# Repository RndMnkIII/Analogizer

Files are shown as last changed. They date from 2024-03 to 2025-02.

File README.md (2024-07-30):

<p float="left">
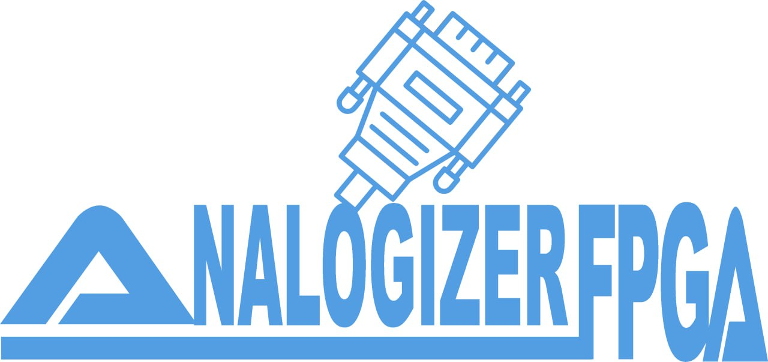
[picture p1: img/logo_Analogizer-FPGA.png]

</p>

Ahora tienes toda la información de Analogizer-FPGA en la [Wiki](https://github.com/RndMnkIII/Analogizer/wiki)

Now you have all the information about Analogizer-FPGA in the [Wiki](https://github.com/RndMnkIII/Analogizer/wiki)

[Tienda Online/Online Store](https://www.analogizer-fpga.com)

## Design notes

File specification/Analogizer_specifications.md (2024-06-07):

# Analogizer Specifications

## Hardware 
* Based on the ADV7123 RGB DAC. It uses 6 bits per color component. It can output video signal with SOG. Supports video frequencies up to 140MHz. 
* RGBS, RGsB, YPbPr, Y/C, RGBHV video output via VGA connector.
* USB 3 connector for SNAC7 adapters that allows you to connect native game controllers. * Connects to the Analogue Pocket using the cartridge port. 
* External 5V power using USB3 C port. Necessary for powering the active Y/C adapter, activating RGB mode on TV with SCART and powering native game controllers.
* A/B switch to alternate signal layout for SNAC devices.
u* SOG (Analogizer R2) switch to activate Sync On Green functionality.

## Basics
 The basis of the Analogizer adapter is to expand the possibilities of the Analogue Pocket portable console in two fundamental aspects. On the one hand
 allow obtaining an analog video output from the video signals generated by the core before being adapted to the characteristics
 Pocket display. This means using the resolution, refresh rates, sync signals, etc. of the original core as it was.
 implemented to replicate the original system. No preprocessing of any kind is applied beyond adapting certain signals to be able to generate the
 different video outputs (RGBS,RGsB,YPbPr, Y/C,RGBHV). This video signal will be compatible with different types of screens, the main objective
 CRT displays with an operating frequency of 15KHz and with different types of video input: SCART RGB, SCART SVideo, SCART Composite, video
 component with YPbPr, SVideo, composite video. Additionally, using a scandoubler module, there will be the possibility of viewing the video using
 SVGA monitors. On the other hand, we want to add the possibility of using native game controllers with the Pocket cores. This is achieved using
 the already established base of official SNAC adapters for MiSTEr that use the SNAC7 protocol and USB 3 type A connector. Analogizer today
 offers SNAC support for 1/2 players for NeoGeo DB15, NES, SNES type controllers. Additionally, it offers 1-player support for PCEngine controllers.
 2 and 6 buttons. This support expands to 4 players using NEC's 5-player multitap adapter. For PCEngine type controls and NEC multitap
 It is necessary to use a wiring harness between the SNAC adapter and the Analogizer due to certain limitations of the Analogizer adapter (it does not have freedom
 to configure SNAC signals as input or output on an individual level and certain signals have a fixed output or input configuration) due to how
 The Pocket's cartridge expansion port works. The adapter has a side switch marked A/B, the default position being A. This
 affects the layout of signals for the SNAC port. Configuration A supports the types of controls listed above. B is reserved for
 future expansions, for example to support PSX controllers. All of this functionality consumes logic resources directly from the Pocket's Cyclone V FPGA.
 that must be shared with the implementation of the core in question to which you want to add support.

## Video output signals
 The main use of Analogizer is that it allows you to obtain different types of analog video signals. It is essential to implement all of them, especially
 the Y/C output for SVideo and composite video, taking into account that most of the CRT TV devices available to users only have this
 video inputs, followed by users with TVs with component video inputs and TVs with SCART inputs. SVGA output is considered accessory for users
 They do not have CRT TV screens but they do have SVGA video monitors.
 In order of video output quality on CRT, the following are recommended:
 * SCART RGB
 * YPbpr component video (requires R2 version of Analogizer with SOG)
 * Y/C SVideo
 * Y/C composite video
 * SVGA

 This table establishes the type of cable and/or adapter necessary depending on the type of video output:
 | VIDEO SIGNAL    | CABLE AND/OR ADAPTER               | COMMENTS                                                                                                                                |
 | :-------------: | :--------------------------------: | :-------------------------------------------------------------------------------------------------------------------------------------: |
 | RGBS            | VGA TO SCART                       | There are specific models that also incorporate a jack-type audio connector. See main repository for more information.                  |
 | RGBS            | VGA TO BNC                         | For CRT models with BNC type inputs. These are normally PVM type professional range screens.                                            |
 | RGsB            | VGA TO SCART                       | Similar to YPbPr but uses RGB channels with sync on G channel. Requires Analogizer R2 with SOG switch (ON position)                     |
 | RGsB            | VGA TO component                   | Similar to YPbPr but uses RGB channels with sync on G channel. Requires Analogizer R2 with SOG switch (ON position)                     |
 | YPbPr           | VGA TO component                   | This cable has 3 RCA cables on the other end. Requires the use of Analogizer R2 with SOG switch (ON position)                           |
 | Y/C             | Active Y/C adapter + cable         | SVideo cable with MiniDIN4 connector or composite video cable with RCA connector.                                                       |
 | RGBHV           | VGA                                | VGA cable to connect directly to a monitor of this type.                                                                                |

## SNAC adapters for controllers
 The second most important functionality that Analogizer offers is that it allows you to use SNAC7 adapters with a USB 3 (type A) connector that already exist in Analogizer with certain limitations.
 This means that you can currently use native controllers for Neogeo DB15, NES, SNES and PCEngine 2btn and 6btn connectors and the NEC 5-player MultiTap adapter (currently 
 you are limited to 4 players by the Analogizer interface). That said, there are countless designs that in most cases will work without problems. In the README of the main Analogizer repository, the different types of adapters compatible with Analogizer will be added, there are versions for both 1 controller and 2 controllers (DB15, NES, SNES). For controls of the type
 PCEngine is also required to have a wiring harness specifically created for Analogizer (it is available for sale in the Analogizer online store and the pcb design is public for users interested in building it themselves). At one end it is connected to the SNAC adapter through a USB 3 female type A connector and at the other end it is
 connects Analogizer with a USB 3 male type A connector. USB 3 female-male extension cables can be used at the convenience of users and is the recommended connection method to avoid
 Excessive stress on the connectors if all these adapters are connected together directly.

 It must be taken into account that the Blue212 type SNAC adapters use two boards (one of them is specific to the native control and has the native connector but does not have its own circuitry). The other board is a common design for all controls and is connected directly to the previous one, it provides all the electronics to convert voltage levels between the controls signals.
 and Analogizer.

## Analogizer interface (development)
The first modification that must be added to the original core code is to enable the Pocket's cartridge port. To do this we must edit the `core.json` file located in the same location as the core bitstream and set `"cartridge_adapter"` to the value`0`:

```
{
  "core": {
    "magic": "APF_VER_1",
    ...
        "framework": {
      "target_product": "Analogue Pocket",
      ...
         "hardware": {
           "link_port": false,
           "cartridge_adapter": 0
         },
```

As the creator of Analogizer I have also developed an interface in Verilog that encapsulates all the functionality in a single module that must be instantiated.
This module is the one that connects the different parts involved so that everything works correctly.

This module communicates with the adapter directly through the Pocket's cartridge expansion port. This port is available in the framework
of Analogue openFPGA for the developer, using the following signals instantiated in the highest level module as follows:

```
module apf_top \(
...
        ///////////////////////////////////////////////////
        // cartridge interface
        // switches between 3.3v and 5v mechanically
        // output enable for multibit translators controlled by PIC32

        // GBA AD[15:8]
        inout   wire    [7:0]   cart_tran_bank2,
        output  wire            cart_tran_bank2_dir,

        // GBA AD[7:0]
        inout   wire    [7:0]   cart_tran_bank3,
        output  wire            cart_tran_bank3_dir,

        // GBA A[23:16]
        inout   wire    [7:0]   cart_tran_bank1,
        output  wire            cart_tran_bank1_dir,

        // GBA [7] PHI#
        // GBA [6] WR#
        // GBA [5] RD#
        // GBA [4] CS1#/CS#
        //     [3:0] unwired
        inout   wire    [7:4]   cart_tran_bank0,
        output  wire            cart_tran_bank0_dir,

        // GBA CS2#/RES#
        inout   wire            cart_tran_pin30,
        output  wire            cart_tran_pin30_dir,
        // when GBC cart is inserted, this signal when low or weak will pull GBC /RES low with a special circuit
        // the goal is that when unconfigured, the FPGA weak pullups won't interfere.
        // thus, if GBC cart is inserted, FPGA must drive this high in order to let the level translators
        // and general IO drive this pin.
        output  wire            cart_pin30_pwroff_reset,

        // GBA IRQ/DRQ
        inout   wire            cart_tran_pin31,
        output  wire            cart_tran_pin31_dir,
		...
  \)
``` 

Normally the `openFPGA_Pocket_Analogizer` module is instantiated at a lower level, where the core module is instantiated.
The only thing that is required is to connect the required signals between the core of the machine that is going to be executed and the instance of the module.
Analogizer:

| SIGNAL | TYPE | WIDTH | FUNCTION |
| :---: | :---: | :---: | :---: |
| MASTER_CLK_FREQ | PARAMETER| | This parameter is used to calculate the delay in timing signals for SNAC |
| i_clk | INPUT | 1 | main clock. It can be the core master clock or the video clock. |
| i_rst | INPUT | 1 | reset signal active at high. Resets the interface and keeps the cartridge port in the default state |
| i_ena | INPUT | 1 | enable signal. If disabled, it keeps the cartridge port in the default state |
| analog_video_type | INPUT | 4 | Select Analogizer video output through the video output port |
| R | INPUT | 8 | color channel R. Internally it is reduced to the 6 bits with the highest weight |
| G | INPUT | 8 | color channel G. Internally it is reduced to the 6 bits with the highest weight |
| B | INPUT | 8 | color channel B. Internally it is reduced to the 6 bits with the highest weight |
| HBlank | INPUT | 1 | horizontal blanking signal |
| VBlank | INPUT | 1 | vertical blanking signal |
| BLANKn | INPUT | 1 | active low composite blanking signal \(ADV7123 requires it for RGBS, RGsB video output\) |
| Hsync | INPUT | 1 | horizontal synchronization signal |
| Vsync | INPUT | 1 | vertical synchronization signal |
| Csync | INPUT | 1 | composite synchronization signal. The generation of this signal is specific to each core |
| video_clk | INPUT | 1 | video clock for the ADV7123. Depending on the core, this signal may be the same as i_clk or another specific |
| PALFLAG | INPUT | 1 | Y/C specific signal. Allows you to adapt SVideo and composite video to PAL\(=1\) or NTSC\(=0\) |
| MUFLAG | INPUT | 1 | specific Y/C signal \(DEBUG\). Modifies the way the phase accumulator is calculated (default =0) |
| CHROMA_ADD | INPUT | 5 | specific Y/C signal \(DEBUG\). Allows you to adjust the value of the phase accumulator in the development phase  |
| CHROMA_MULT | INPUT | 5 | specific Y/C signal \(DEBUG\). Allows you to adjust the value of the phase accumulator in the development phase  |
| CHROMA_PHASE_INC | INPUT | 40 | Y/C specific signal. Tuned phase accumulator step value for core frequency |
| COLORBURST_RANGE | INPUT | 27 | Y/C specific signal. Tuned color burst value for core video frequency |
| ce_divider | INPUT | 3 | Scandoubler RGBHV specifies signal. Pixel clock divider. Use value that best fits the image |
| conf_AB | INPUT | 1 | SNAC signal. Configuration A\(=0\) or B\(=1\) for SNAC. It must match the position of the A/B switch |
| game_cont_type | INPUT | 5 | SNAC signal. Specifies if SNAC commands are not used and if what type are used (See interact.json file) |
| p1_btn_state | OUTPUT | 16 | SNAC signal. Status of SNAC control buttons for player1 \(ST,SEL,R3,L3,R2,L2,R1,L1,Y,X,B,A,R,L,D,U\) |
| p2_btn_state | OUTPUT | 16 | SNAC signal. Status of SNAC control buttons for player2 \(ST,SEL,R3,L3,R2,L2,R1,L1,Y,X,B,A,R,L,D,U\) |
| p3_btn_state | OUTPUT | 16 | SNAC signal. Status of SNAC control buttons for player3 \(ST,SEL,R3,L3,R2,L2,R1,L1,Y,X,B,A,R,L,D,U\) |
| p4_btn_state | OUTPUT | 16 | SNAC signal. Status of SNAC control buttons for player4 \(ST,SEL,R3,L3,R2,L2,R1,L1,Y,X,B,A,R,L,D,U\) |
| cart_tran_bank2 | I/O | 8 | Interface with the cartridge port. Connects directly to the signals of the higher level module |
| cart_tran_bank2_dir | OUTPUT | 1 | Interface with the cartridge port. Connects directly to the signals of the higher level module |
| cart_tran_bank3 | I/O | 8 | Interface with the cartridge port. Connects directly to the signals of the higher level module |
| cart_tran_bank3_dir | OUTPUT | 1 | Interface with the cartridge port. Connects directly to the signals of the higher level module |
| cart_tran_bank1 | I/O | 8 | Interface with the cartridge port. Connects directly to the signals of the higher level module |
| cart_tran_bank1_dir | OUTPUT | 1 | Interface with the cartridge port. Connects directly to the signals of the higher level module |
| cart_tran_bank0 | I/O | 4 | Interface with the cartridge port. Connects directly to the signals of the higher level module |
| cart_tran_bank0_dir | OUTPUT | 1 | Interface with the cartridge port. Connects directly to the signals of the higher level module |
| cart_tran_pin30 | I/O | 1 | Interface with the cartridge port. Connects directly to the signals of the higher level module |
| cart_tran_pin30_dir | OUTPUT | 1 | Interface with the cartridge port. Connects directly to the signals of the higher level module |
| cart_pin30_pwroff_reset| OUTPUT | 1 | Interface with the cartridge port. Connects directly to the signals of the higher level module |
| cart_tran_pin31 | I/O | 1 | Interface with the cartridge port. Connects directly to the signals of the higher level module |
| cart_tran_pin31_dir | OUTPUT | 1 | Interface with the cartridge port. Connects directly to the signals of the higher level module |
| o_stb | OUTPUT | 1 | Interface with the cartridge port. Connects directly to the signals of the higher level module |

So that the user can modify the Analogizer options, three groups of options are established. These options are usually set in the `interact.js` file which is in the same location as the core bitstream. This may change in the case of cores that have different options depending on the game you want to load:

```
{
  "interact": {
    "magic": "APF_VER_1",
    "variables": [
       {
        "name": "SNAC Adapter",
        "id": 43,
        "type": "list",
        "enabled": true,
        "persist": true,
        "address": "0xA0000000",
        "defaultval": "0x00",
        "mask": "0xFFFFFFE0",
        "options": [
            {
            "value": "0x00",
            "name": "None"
            },
            {
            "value": "0x01",
            "name": "DB15 Normal"
            },
            {
            "value": "0x02",
            "name": "NES"
            },
            {
            "value": "0x03",
            "name": "SNES"
            },
            {
            "value": "0x04",
            "name": "PCE 2BTN"
            },
            {
            "value": "0x05",
            "name": "PCE 6BTN"
            },
            {
            "value": "0x06",
            "name": "PCE Multitap"
            },
            {
              "value": "0x09",
              "name": "DB15 Fast"
            },
            {
              "value": "0x0B",
              "name": "SNES A,B<->X,Y"
            }
        ]
    },
    {
        "name": "SNAC Controller Assignment",
        "id": 44,
        "type": "list",
        "enabled": true,
        "persist": true,
        "address": "0xA0000000",
        "defaultval": "0x00",
        "mask": "0xFFFFFC3F",
        "options": [
            {
              "value": "0x0",
              "name": "SNAC -> P1"
            },
            {
              "value": "0x40",
              "name": "SNAC -> P2"
            },
            {
              "value": "0x80",
              "name": "SNAC P1,P2->P1,P2"
            },
            {
              "value": "0xC0",
              "name": "SNAC P1,P2->P2,P1"
            },
            {
              "value": "0x200",
              "name": "SNAC P1,P2->P3,P4"
            },
            {
              "value": "0x100",
              "name": "SNAC P1-P4->P1-P4"
            },
            {
              "value": "0x140",
              "name": "SNAC P1-P2->P1-P2"
            },
            {
              "value": "0x180",
              "name": "SNAC P1-P2->P3-P4"
            }
        ]
    },
    {
        "name": "Analogizer Video Out",
        "id": 45,
        "type": "list",
        "enabled": true,
        "persist": true,
        "address": "0xA0000000",
        "defaultval": "0x0",
        "mask": "0xFFFFC3FF",
        "options": [
            {
              "value": "0x0",
              "name": "RGBS"
            },
            {
              "value": "0x0400",
              "name": "RGsB"
            },
            {
              "value": "0x0800",
              "name": "YPbPr"
            },
            {
              "value": "0x0C00",
              "name": "Y/C NTSC"
            },
            {
              "value": "0x1400",
              "name": "Scandoubler RGBHV"
            },
            {
              "value": "0x2000",
              "name": "RGBS,Pocket OFF"
            },
            {
              "value": "0x2400",
              "name": "RGsB,Pocket OFF"
            },
            {
              "value": "0x2800",
              "name": "YPbPr,Pocket OFF"
            },            {
              "value": "0x2C00",
              "name": "Y/C NTSC,Pocket OFF"
            },
            {
              "value": "0x3400",
              "name": "Scandoubler,Pocket OFF"
            }
        ]
    },
    ...
        ],
    "messages": []
  }
}
```

In a schematic way, these would be the different options that can be selected for Analogizer:

```
  SNAC Adapter
    |                            FUNCTION                    VALUE (hex) WIDTH ADDRESS    MASK       MASKED VALUE
    +----------- None            disables SNAC interface     0x0         5     0xA0000000 0xFFFFFFE0 0x00        
    +----------- DB15 Normal     1/2 players                 0x1         5     0xA0000000 0xFFFFFFE0 0x01        
    +----------- NES             1/2 players                 0x2         5     0xA0000000 0xFFFFFFE0 0x02        
    +----------- SNES            1/2 players                 0x3         5     0xA0000000 0xFFFFFFE0 0x03         
    +----------- PCE 2BTN        1 player                    0x4         5     0xA0000000 0xFFFFFFE0 0x04         
    +----------- PCE 6BTN        1 player                    0x5         5     0xA0000000 0xFFFFFFE0 0x05         
    +----------- PCE Multitap    allows 4 players            0x6         5     0xA0000000 0xFFFFFFE0 0x06         
    +----------- DB15 Fast       uses faster sampling        0x9         5     0xA0000000 0xFFFFFFE0 0x09         
    +----------- SNES A,B<->X,Y  swap A,B X,Y buttons        0xB         5     0xA0000000 0xFFFFFFE0 0x0B         
``` 

```
  SNAC Controller Assignment 
    |                              FUNCTION                                       VALUE (hex) WIDTH ADDRESS    MASK       MASKED VALUE
    +----------- SNAC -> P1        SNAC controller to P1                          0x0         4     0xA0000000 0xFFFFFC3F 0x000                 
    +----------- SNAC -> P2        SNAC controller to P2                          0x1         4     0xA0000000 0xFFFFFC3F 0x040           
    +----------- SNAC P1,P2->P1,P2 SNAC cont1,cont2 to P1,P2                      0x2         4     0xA0000000 0xFFFFFC3F 0x080           
    +----------- SNAC P1,P2->P2,P1 SNAC cont1,cont2 to P2,P1                      0x3         4     0xA0000000 0xFFFFFC3F 0x0C0           
    +----------- SNAC P1,P2->P3,P4 SNAC cont1,cont2 to P3,P4 (only for 4P cores)  0x8         4     0xA0000000 0xFFFFFC3F 0x200           
    +----------- SNAC P1-P4->P1-P4 SNAC cont1-cont4 to P1-P4 (only for 4P cores)  0x9         4     0xA0000000 0xFFFFFC3F 0x100           
    +----------- SNAC P1-P2->P1-P2 SNAC cont1-cont2 to P1-P2 (only for 4P cores)  0xA         4     0xA0000000 0xFFFFFC3F 0x140           
    +----------- SNAC P1-P2->P3-P4 SNAC cont1-cont2 to P3-P4 (only for 4P cores)  0xB         4     0xA0000000 0xFFFFFC3F 0x180                     
```

```
  Analogizer Video Out
    |                                   FUNCTION                    VALUE (hex) WIDTH ADDRESS    MASK       MASKED VALUE 
    +----------- RGBS                   idem                        0x0         4     0xA0000000 0xFFFFC3FF 0x0000       
    +----------- RGsB                   idem                        0x1         4     0xA0000000 0xFFFFC3FF 0x0400       
    +----------- YPbPr                  idem                        0x2         4     0xA0000000 0xFFFFC3FF 0x0800       
    +----------- Y/C NTSC               idem                        0x3         4     0xA0000000 0xFFFFC3FF 0x0C00       
    +----------- Y/C PAL                idem                        0x4         4     0xA0000000 0xFFFFC3FF 0x1000       
    +----------- Scandoubler RGBHV      idem                        0x5         4     0xA0000000 0xFFFFC3FF 0x1400       
    +----------- RGBS,Pocket OFF        idem, blanks Pocket screen  0x8         4     0xA0000000 0xFFFFC3FF 0x2000       
    +----------- RGsB,Pocket OFF        idem, blanks Pocket screen  0x9         4     0xA0000000 0xFFFFC3FF 0x2400       
    +----------- YPbPr,Pocket OFF       idem, blanks Pocket screen  0xA         4     0xA0000000 0xFFFFC3FF 0x2800       
    +----------- Y/C NTSC,Pocket OFF    idem, blanks Pocket screen  0xB         4     0xA0000000 0xFFFFC3FF 0x2C00       
    +----------- Y/C PAL,Pocket OFF     idem, blanks Pocket screen  0xC         4     0xA0000000 0xFFFFC3FF 0x3000       
    +----------- Scandoubler,Pocket OFF idem, blanks Pocket screen  0xD         4     0xA0000000 0xFFFFC3FF 0x3400         
```

A range of bridge addresses must be selected in the Pocket framework. In the example, address 0xA0000000 has been reserved for Analogizer.
The interaction in the code is up to the developer, in this example it would look like this:

```
  // for bridge write data, we just broadcast it to all bus devices
  // for bridge read data, we have to mux it
  // add your own devices here
  always @(*) begin
    casex (bridge_addr)
      default: begin
        bridge_rd_data <= 0;
      end
      32'h2xxxxxxx: begin
        bridge_rd_data <= sd_read_data;
      end
      32'hA0000000: begin //Analogizer settings
        bridge_rd_data <= {18'h0,analogizer_settings};
      end
      32'hF8xxxxxx: begin
        bridge_rd_data <= cmd_bridge_rd_data;
      end
    endcase
  end
```

```
 always @(posedge clk_74a) begin
    if (reset_delay > 0) begin
      reset_delay <= reset_delay - 1;
    end

    if (bridge_wr) begin
      casex (bridge_addr)
        32'h0: begin
          ioctl_download <= bridge_wr_data[0];
        end
        32'h4: begin
          save_download <= bridge_wr_data[0];
        end
        ...
        /*[ANALOGIZER_HOOK_BEGIN]*/
		32'hA0000000: analogizer_settings  <=  bridge_wr_data[13:0];
	    /*[ANALOGIZER_HOOK_END]*/
        ...
      endcase
    end
  end
```

It may be necessary to synchronize the reading of the options, when using different clock domains:

```
  /*[ANALOGIZER_HOOK_BEGIN]*/
  //Pocket Menu settings
  reg [13:0] analogizer_settings = 0;
  wire [13:0] analogizer_settings_s;

  synch_3 #(.WIDTH(14)) sync_analogizer(analogizer_settings, analogizer_settings_s, clk_sys_42_95);

  always @(*) begin
    snac_game_cont_type   = analogizer_settings_s[4:0];
    snac_cont_assignment  = analogizer_settings_s[9:6];
    analogizer_video_type = analogizer_settings_s[13:10];
  end
  /*[ANALOGIZER_HOOK_END]*/
```

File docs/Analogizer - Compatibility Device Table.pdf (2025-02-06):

USER | MANUFACTURER | MODEL | SCREEN TYPE | COLOR SYSTEM | VIDEO INPUT | STATUS | YEAR @rndmnkiii | SONY | PVM-9044D | CRT HR Trinitron (450 lines) | PAL/SECAM,NTSC | Y/C(4pin MiniDIN); COMPOSITE, RGBS, YPBPR,RGsB (BNC) | NTSC and PAL works @rndmnkiii | SONY | KV-M1420E | CRT Trinitron | PAL | RGBS (SCART), COMPOSITE (RCA) | PAL works(RGB SCART,composite), NTSC works(RGB SCART)
@HardBit | SONY | KV-14FV300 | CRT | NTSC | YPBPR | OK @Denymetanol | SONY | EVM-9010PR | CRT | PAL | COMPOSITE | OK @Denymetanol | NEC | MultiSync LV15m | LCD | SVGA | RGBHV | OK @RetroQuest | SONY | CRT | NTSC | COMPOSITE | OK @unlovedhomie | NEC | MultiSync 1560V+ | LCD | SVGA | RGBHV | OK @unlovedhomie | SONY | CRT | NTSC | YPBPR | YPbPr don't sync
| JVC | AV-27120 27" | CRT | NTSC | COMPOSITE SVIDEO YPbPr | ? | sept 2000
@romanista | SHARP | 37GT 27S | CRT | PAL | RGBS SCART | OK

USER | CABLE TYPE | WEBSITE | NOTES
rndmnkiii | VGA TO SCART | https://manuferhi.com/p/cable-rgb-scart-for-mister-sidi-and-n-go | built-in audio jack cable, 470ohms in CSYNC resistor
rndmnkiii | VGA TO SCART | https://ultimatemister.com/product/rgb-scart-cable/ | built-in audio jack cable, 470ohms in CSYNC resistor
rndmnkiii | VGA TO BNC COAX. | https://www.amazon.es/dp/B0CWP9X1Z8?ref=ppx_yo2ov_dt_b_fed_asin_title | used to connect to a Sony PVM, needs 4 cables:R,G,B,Csync
rndmnkiii | VGA TO VGA | any cable
rndmnkiii | VGA gender changer | any adapter
rndmnkiii | RCA TO BNC | https://www.amazon.es/dp/B017R6XXFS?ref=ppx_yo2ov_dt_b_fed_asin_title | used to connect Mike Simone Y/C adapter (composite) to a Sony PVM
rndmnkiii | SVIDEO | https://www.amazon.es/dp/B000MM3LNO?ref=ppx_yo2ov_dt_b_fed_asin_title&th=1 | used to connect Mike Simone Y/C adapter (SVideo) to a Sony PVM

USER | PSX SNAC TYPE | PORTS 2 | https://analogizer-fpga.com/products/psx-snac-adapter-usb-3-type-a-male-female-cable WEBSITE | NOTES @rndmnkiii
@rndmnkiii | DB15 | 2 | https://ultimatemister.com/product/snac-db15-neogeo/
@rndmnkiii | NES,SNES,PCEngine/TurboGrafx-16 | 1-2 | https://ultimatemister.com/product/ultimate-snac-mini-hdmi/ | needs matching game controller cable
@rndmnkiii | DB15,NES,SNES,PCEngine/TurboGrafx-16 | 1-2 | https://antoniovillena.com/product/splitter-for-official-mister/ | specific models for each game controller
@rndmnkiii | NES,SNES,PCEngine/TurboGrafx-16 | 1-2 | https://misterfpga.co.uk/product/mister-snac-adapter-usb/ | needs matching game controller board: https://misterfpga.co.uk/product/mister-snac-controller-adapters/
@rndmnkiii | PSX | 2 | https://misterfpga.co.uk/product/mister-snac-playstation-psx-adapter/
@rndmnkiii | PSX | 2 | https://manuferhi.com/p/mister-snac-playstation-adapter

USER | TYPE | WEBSITE | NOTES
rndmnkiii | 8Bitdo SNES Retroreceiver | https://www.8bitdo.com/retro-receiver-snes-sfc-classic/ | Allows, using a SNES SNAC adapter, connect a wide selection of Bluetooth game controllers to Analogizer: * 8BitDo Bluetooth Classic controllers and arcade sticks: https://shop.8bitdo.com/collections/bluetooth-controller * Xbox Bluetooth® controller, DualShock 3, DualShock 4, DualShock 4 Pro * Wiimote, Wii U Pro, Switch Joy-Cons, Switch Pro
rndmnkiii | 8Bitdo PSX Retroreceiver | https://www.8bitdo.com/retro-receiver-for-ps/ | Allows, using a PSX SNAC adapter, connect a wide selection of Bluetooth game controllers to Analogizer: * 8BitDo Bluetooth Classic controllers and arcade sticks: https://shop.8bitdo.com/collections/bluetooth-controller * Xbox Bluetooth® controller, DualShock 3, DualShock 4, DualShock 4 Pro * Wiimote, Wii U Pro, Switch Joy-Cons, Switch Pro
rndmnkiii | JAMMA TO SNAC DB15 Uses JAMMA Arcade cabinet controls as aDB15 SNAC two player controller (don't needs a DB15 SNAC adapter to be used with Analogizer). THIS ADAPTER IS INTENDED FOR ADVANCED USER, don't use it If you are not comfortable regulating voltage sources or you don't have basic knowledge of electronics. You could damage the adapter or the Pocket itself.
rndmnkiii | GENESIS/MEGADRIVE PAD TO NEOGEO ADAPTER Allows to connect a 3/6 button Genesis game controller to a DB15 SNAC adapter. The DB15 SNAC adapter must be output 5v throught the DB15 power pin. | https://www.ebay.es/itm/156101614172

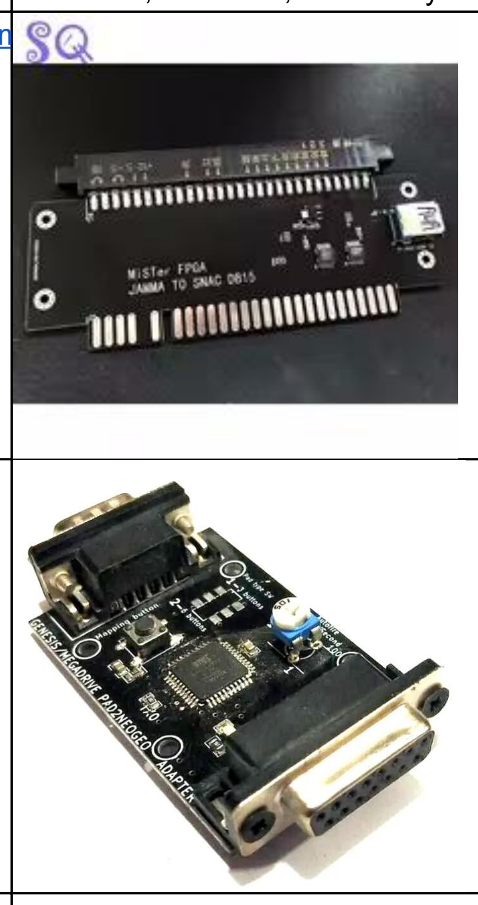
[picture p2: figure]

https://es.aliexpress.com/item/1005004883345268.html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

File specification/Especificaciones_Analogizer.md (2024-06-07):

# Especificaciones de Analogizer
## Hardware
* Basado en el DAC RGB ADV7123. Utiliza 6 bits por componente de color. Puede generar salida con SOG.Admite frecuencias de video de hasta 140MHz.
* Salida de video RGBS,RGsB,YPbPr,Y/C,RGBHV a través de conector VGA.
* Conector USB 3 para adaptores SNAC7 que permite conectar mandos de juegos nativos.
* Se conecta a la Analogue Pocket Utilizando el puerto de cartuchos.
* Alimentación externa de 5V utilizando puerto USB3 C. Necesaria para alimentacion de adaptador activo Y/C, activación de modo RGB en TV con SCART y alimentación de mandos de juegos nativos.
* Interruptor A/B para alternar disposicion de señales para dispositivos SNAC.
* Interruptor SOG (Analogizer R2) para activar funcionalidad Sync On Green.

## Fundamentos
 El fundamento del adaptador Analogizer es ampliar las posibilidades de la consola portatil Pocket de Analogue en dos aspectos fundamentales. Por un lado
 permitir obtener una salida de video analógica a partir de las señales de video que genera el core antes de ser adaptadas a las características
 de visualización de la Pocket. Esto implica usar la resolución, frecuencias de refresco, señales de sincronismo, etc del core original tal como fue
 implementado para replicar el sistema original. No se aplica preprocesado de ningún tipo más allá de adaptar ciertas señales para poder generar las
 diferentes salidas de video (RGBS,RGsB,YPbPr, Y/C,RGBHV). Esta señal de video será compatible con diferentes tipos de pantalla, el objetivo principal
 pantallas CRT con una frecuencia de funcionamiento de 15KHz y con diferentes tipos de entrada de video: SCART RGB, SCART SVideo, SCART Composite, video
 por componentes con YPbPr, SVideo, video compuesto. Además utilizando un módulo scandoubler se habre la posibilidad de visualizar el video utilizando
 monitores SVGA. Por otro lado se quiere añadir la posibilidad de utilizar mandos de juegos nativos con los cores de la Pocket. Esto se logra utilizando
 la base ya establecida de adaptadores SNAC oficiales para MiSTEr que utilizan el protocolo SNAC7 y conector USB 3 del tipo A. Analogizer en la actualidad
 ofrece soporte SNAC para 1/2 jugadores para los mandos de tipo NeoGeo DB15, NES, SNES. Adicionalmente ofrece soporte para 1 jugador para mandos PCEngine de
 2 y 6 botones. Este suporte se amplia a 4 jugadores utilizando el adaptador multitap de 5 jugadores de NEC. Para los mandos de tipo PCEngine y el multitap NEC
 es necesario utilizar un arnés de cableado entre el adaptador SNAC y el Analogizer debido a ciertas limitaciones del adaptador Analogizer (no tiene libertad
 para configurar las señales SNAC como de entrada o salida a nivel individual y ciertas señales tienen un configuración fija de salida o entrada) debidas a como
 funciona el puerto de expansión de cartuchos de la Pocket. El adaptador dispone de un switch lateral marcado con A/B, siendo la posición por defecto la A. Esto
 afecta a la disposicion de las señales para el puerto SNAC. Con la configuración A se da soporte a los tipos de mandos antes enumerados. La B se reserva para
 futuras ampliciones, por ejemplo para dar soporte a los mandos PSX. Toda esta funcionalidad consume recursos lógicos directamente de la FPGA Cyclone V de la Pocket
 que deben ser compartidos con la implementación del core en cuestión al que se le quiere añadir soporte.

## Señales de salida de video
 La principal utilidad de Analogizer es que permite obtener diferentes tipos de señales de video analógicas. Es fundamental implementar todas ellas, especialmente
 la salida Y/C para SVideo y video compuesto, teniendo en cuenta que la mayor parte de los dispositivos CRT TV de los que disponen los usuarios solo dispone de esta
 entradas de video, seguidos por los usuarios con TV con entrada de video por componentes y TV con entrada SCART. La salida SVGA se considera accesoria para usuarios
 que no disponen de pantallas de TV CRT pero si disponen de monitores de video SVGA.
 Por orden de calidad de salida de video en CRT se recomiendan: 

 * SCART RGB
 * Video por componentes YPbpr (requiere versión R2 de Analogizer con SOG)
 * Y/C SVideo
 * Y/C video compuesto
 * SVGA
  
 En esta tabla se establece el tipo de cable y/o adaptador necesario en función del tipo de salida de video:
 
 | SEÑAL DE VIDEO  | CABLE Y/O ADAPTADOR                | COMENTARIOS                                                                                                                           |
 | :-------------: | :--------------------------------: | :-----------------------------------------------------------------------------------------------------------------------------------: |
 | RGBS            | VGA TO SCART                       | Hay modelos especificos que incorporan tambien el conector de audio de tipo jack. Ver repositorio principal para mas información.     |
 | RGBS            | VGA TO BNC                         | Para modelos de CRT con entradas de tipo BNC. Normalmente se trata de pantallas de gama profesional de tipo PVM.                      |
 | RGsB            | VGA TO SCART                       | Parecido a YPbPr pero usa canales RGB con el sync en el canal G. Necesita Analogizer R2 con interruptor SOG (posicion ON)             | 
 | RGsB            | VGA TO component                   | Parecido a YPbPr pero usa canales RGB con el sync en el canal G. Necesita Analogizer R2 con interruptor SOG (posicion ON)             | 
 | YPbPr           | VGA TO component                   | esta cable tiene 3 cables RCA en el otro extremo. Requiere el uso de Analogizer R2 con interruptor SOG (posicion ON)                  |
 | Y/C             | Active Y/C adapter + cable         | Cable SVideo con conector MiniDIN4 o cable de video compuesto con conector RCA.                                                       |
 | RGBHV           | VGA                                | Cable VGA para conectar directamente a un monitor de este tipo.                                                                       |

## Adaptores SNAC para mandos
 La segunda funcionalidad en importancia que ofrece Analogizer es que permite usar adaptadores SNAC7 con conector USB 3 (tipo A) ya existentes en Analogizer con ciertas limitaciones.
 Este se traduce en que en la actualidad puedes utilizar mandos nativos que usen conectores Neogeo DB15, NES, SNES y PCEngine de 2 y 6 botones y el adaptador MultiTap NEC de 5 jugadores (actualmen
 te limitado a 4 jugadores por la interfaz de Analogizer). Dicho esto existen una infinidad de diseños que en la mayoría de los casos funcionarán sin problemas. En el README del repositorio principal de Analogizer se irán añadiendo los diferentes tipos de adaptadores compatibles con Analogizer, existen versiones tanto para 1 mando como para 2 mandos (DB15,NES,SNES). Para los mandos del tipo
 PCEngine se requiere además de un arnés de cableado especificamente creado para analogizer (está disponible a la venta en la tienda online de Analogizer y además el diseño del pcb es público para los usuarios interesados en construirlo ellos mismos). En un extremo se conecta al adaptador SNAC por un conector USB 3 hembra de tipo A y por el otro extremo se
 conecta a Analogizer con un conector USB 3 macho de tipo A. Se pueden usar cables extensores USB 3 hembra-macho a conveniencia de los usuarios y es el método de conexión recomendado para evitar
 excsivo estress de los conectores si se conectan todos estos adaptadores entre sí directamente.
 Hay que tener en cuenta que los adaptadores SNAC de tipo Blue212 usa dos placas (una de ellas es especifica del mando nativo y tiene el conector nativo pero no posee circuiteria propia). La otra placa es un diseño común para todos los mandos y se conecta directamente a la anterior, esta provee toda la electrónica para hacer la conversión de niveles de voltage entre las señales de los mandos
 y Analogizer. 

## Interfaz Analogizer (desarrollo)
La primera modificación que hay que añadir al código del core original es habilitar el puerto de cartuchos de la Pocket. Para ello debemos editar el archivo `core.json` que se encuentra en la misma ubicación que el bitstream del core y establecer `"cartridge_adapter"` al valor `0`:

```
{
  "core": {
    "magic": "APF_VER_1",
    ...
        "framework": {
      "target_product": "Analogue Pocket",
      ...
         "hardware": {
           "link_port": false,
           "cartridge_adapter": 0
         },
```

Como creador del Analogizer he desarrollado también una interfaz en Verilog que encapsula toda la funcionalidad en un único módulo que hay que instanciar.
Dicho modulo es el que conecta las diferentes partes implicadas para que funcione todo de manera correcta.
Este módulo se comunica con el adaptador directamente a través del puerto de expansión de cartuchos de la Pocket. Este puerto está disponible en el framework
de Analogue openFPGA para el desarrollador, utilizando las siguientes señales instanciadas en el módulo de mas alto nivel como sigue:
```
module apf_top (
...
        ///////////////////////////////////////////////////
        // cartridge interface
        // switches between 3.3v and 5v mechanically
        // output enable for multibit translators controlled by PIC32

        // GBA AD[15:8]
        inout   wire    [7:0]   cart_tran_bank2,
        output  wire            cart_tran_bank2_dir,

        // GBA AD[7:0]
        inout   wire    [7:0]   cart_tran_bank3,
        output  wire            cart_tran_bank3_dir,

        // GBA A[23:16]
        inout   wire    [7:0]   cart_tran_bank1,
        output  wire            cart_tran_bank1_dir,

        // GBA [7] PHI#
        // GBA [6] WR#
        // GBA [5] RD#
        // GBA [4] CS1#/CS#
        //     [3:0] unwired
        inout   wire    [7:4]   cart_tran_bank0,
        output  wire            cart_tran_bank0_dir,

        // GBA CS2#/RES#
        inout   wire            cart_tran_pin30,
        output  wire            cart_tran_pin30_dir,
        // when GBC cart is inserted, this signal when low or weak will pull GBC /RES low with a special circuit
        // the goal is that when unconfigured, the FPGA weak pullups won't interfere.
        // thus, if GBC cart is inserted, FPGA must drive this high in order to let the level translators
        // and general IO drive this pin.
        output  wire            cart_pin30_pwroff_reset,

        // GBA IRQ/DRQ
        inout   wire            cart_tran_pin31,
        output  wire            cart_tran_pin31_dir,
		...
)
``` 

Normalmente el módulo `openFPGA_Pocket_Analogizer`se instancia a un nivel mas bajo, donde se crea la instancia del módulo del core.
Lo único que se precisa es conectar las señales requiridas entre el core de la maquina que se va a ejecutar y la instancia del módulo de
Analogizer:

| SEÑAL | TIPO | ANCHO | FUNCION |
| :---: | :---: | :---: | :---: |
| MASTER_CLK_FREQ | PARAMETRO| | Este parámetro se utiliza para calcular el delay en señales de temporización para los dispositivos SNAC |
| i_clk | ENTRADA  | 1 | reloj principal. Puede ser el reloj maestro del core o el reloj de video. |
| i_rst | ENTRADA  | 1 | señal de reset activa a alta. Reinicia la interfaz y mantiene el puerto de cartuchos en estado por defecto |
| i_ena | ENTRADA  | 1 | señal de habilitacion. Si esta deshabilitada mantiene el puerto de cartuchos en el estado por defecto |
| analog_video_type | ENTRADA  | 4 | Selecciona la salida de video de Analogizer a través del puerto de salida de video |
| R | ENTRADA  | 8 | canal de color R. Internamente se reduce a los 6 bits de mayor peso |
| G | ENTRADA  | 8 | canal de color G. Internamente se reduce a los 6 bits de mayor peso |
| B | ENTRADA  | 8 | canal de color B. Internamente se reduce a los 6 bits de mayor peso |
| HBlank | ENTRADA  | 1 | señal de blanking horizontal |
| VBlank | ENTRADA  | 1 | señal de blanking vertical |
| BLANKn | ENTRADA  | 1 | señal de blanking compuesto activa a baja (el ADV7123 la requiere para salida de video RGBS, RGsB) |
| Hsync | ENTRADA  | 1 | señal de sincronismo horizontal |
| Vsync | ENTRADA  | 1 | señal de sincronismo vertical |
| Csync | ENTRADA  | 1 | señal de sincronismo compuesto. La generación de esta señal es específica de cada core |
| video_clk | ENTRADA  | 1 | reloj de video para el ADV7123. Según el core esta señal puede ser la misma que i_clk u otra específica |
| PALFLAG | ENTRADA  | 1 | señal especifica Y/C. Permite adaptar SVideo y el video compuesto a PAL(=1) o a NTSC(=0) |
| MULFLAG | ENTRADA  | 1 | señal especifica Y/C (DEBUG). Modifica la forma en la que se calcula el acumulador de fase (po defecto =0) |
| CHROMA_ADD | ENTRADA  | 5 | señal especifica Y/C (DEBUG). Permite ajustar el valor del acumulador de fase en la fase de desarrollo |
| CHROMA_MULT | ENTRADA  | 5 | señal especifica Y/C (DEBUG). Permite ajustar el valor del acumulador de fase en la fase de desarrollo |
| CHROMA_MULT | ENTRADA  | 5 | señal especifica Y/C (DEBUG). Permite ajustar el valor del acumulador de fase en la fase de desarrollo |
| CHROMA_PHASE_INC | ENTRADA  | 40 | señal especifica Y/C. Valor de incremento del acumulador de fase sintonizado para la frecuencia del core |
| COLORBURST_RANGE | ENTRADA  | 27 | señal especifica Y/C. Valor de color burst sintonizado para la frecuencia de video del core |
| ce_divider | ENTRADA  | 3 | señal especifica Scandoubler RGBHV. Divisor del reloj de pixel. Usar valor que mejor ajuste la imagen |
| conf_AB | ENTRADA  | 1 | señal SNAC. Configuración A (=0) ó B (=1) para SNAC. Debe coincidir con posicion del interruptor A/B |
| game_cont_type | ENTRADA  | 5 | señal SNAC. Especifica si no se usan mandos SNAC y si se usan de que tipo (Ver archivo interact.json) |
| p1_btn_state | SALIDA | 16 | señal SNAC. Estado de los botones de mando SNAC para el player1 (ST,SEL,R3,L3,R2,L2,R1,L1,Y,X,B,A,R,L,D,U) |
| p2_btn_state | SALIDA | 16 | señal SNAC. Estado de los botones de mando SNAC para el player2 (ST,SEL,R3,L3,R2,L2,R1,L1,Y,X,B,A,R,L,D,U) |
| p3_btn_state | SALIDA | 16 | señal SNAC. Estado de los botones de mando SNAC para el player3 (ST,SEL,R3,L3,R2,L2,R1,L1,Y,X,B,A,R,L,D,U) |
| p4_btn_state | SALIDA | 16 | señal SNAC. Estado de los botones de mando SNAC para el player4 (ST,SEL,R3,L3,R2,L2,R1,L1,Y,X,B,A,R,L,D,U) |
| cart_tran_bank2 | E/S | 8 | interfaz con el puerto de cartuchos. Se conecta directamente a la señales del módulo de nivel superior |
| cart_tran_bank2_dir | SALIDA | 1 | interfaz con el puerto de cartuchos. Se conecta directamente a la señales del módulo de nivel superior |
| cart_tran_bank3 | E/S | 8 | interfaz con el puerto de cartuchos. Se conecta directamente a la señales del módulo de nivel superior |
| cart_tran_bank3_dir | SALIDA | 1 | interfaz con el puerto de cartuchos. Se conecta directamente a la señales del módulo de nivel superior |
| cart_tran_bank1 | E/S | 8 | interfaz con el puerto de cartuchos. Se conecta directamente a la señales del módulo de nivel superior |
| cart_tran_bank1_dir | SALIDA | 1 | interfaz con el puerto de cartuchos. Se conecta directamente a la señales del módulo de nivel superior |
| cart_tran_bank0 | E/S | 4 | interfaz con el puerto de cartuchos. Se conecta directamente a la señales del módulo de nivel superior |
| cart_tran_bank0_dir | SALIDA | 1 | interfaz con el puerto de cartuchos. Se conecta directamente a la señales del módulo de nivel superior |
| cart_tran_pin30 | E/S | 1 | interfaz con el puerto de cartuchos. Se conecta directamente a la señales del módulo de nivel superior |
| cart_tran_pin30_dir | SALIDA | 1 | interfaz con el puerto de cartuchos. Se conecta directamente a la señales del módulo de nivel superior |
| cart_pin30_pwroff_reset| SALIDA | 1 | interfaz con el puerto de cartuchos. Se conecta directamente a la señales del módulo de nivel superior |
| cart_tran_pin31 | E/S | 1 | interfaz con el puerto de cartuchos. Se conecta directamente a la señales del módulo de nivel superior |
| cart_tran_pin31_dir | SALIDA | 1 | interfaz con el puerto de cartuchos. Se conecta directamente a la señales del módulo de nivel superior |
| o_stb | SALIDA | 1 | signal used for debugging of the SNAC module in the development phase. Not necessary for normal use |

Para que el usuario pueda modificar las opciones de Analogizer se establecen tres grupos de opciones. Estas opciones se establecen normalmente en el archivo `interact.js` que se encuentra en la misma ubicación que el bitstream del core. Esto puede cambiar en el caso de cores que tienen opciones diferentes en función del juego que se desea cargar:

```
{
  "interact": {
    "magic": "APF_VER_1",
    "variables": [
       {
        "name": "SNAC Adapter",
        "id": 43,
        "type": "list",
        "enabled": true,
        "persist": true,
        "address": "0xA0000000",
        "defaultval": "0x00",
        "mask": "0xFFFFFFE0",
        "options": [
            {
            "value": "0x00",
            "name": "None"
            },
            {
            "value": "0x01",
            "name": "DB15 Normal"
            },
            {
            "value": "0x02",
            "name": "NES"
            },
            {
            "value": "0x03",
            "name": "SNES"
            },
            {
            "value": "0x04",
            "name": "PCE 2BTN"
            },
            {
            "value": "0x05",
            "name": "PCE 6BTN"
            },
            {
            "value": "0x06",
            "name": "PCE Multitap"
            },
            {
              "value": "0x09",
              "name": "DB15 Fast"
            },
            {
              "value": "0x0B",
              "name": "SNES A,B<->X,Y"
            }
        ]
    },
    {
        "name": "SNAC Controller Assignment",
        "id": 44,
        "type": "list",
        "enabled": true,
        "persist": true,
        "address": "0xA0000000",
        "defaultval": "0x00",
        "mask": "0xFFFFFC3F",
        "options": [
            {
              "value": "0x0",
              "name": "SNAC -> P1"
            },
            {
              "value": "0x40",
              "name": "SNAC -> P2"
            },
            {
              "value": "0x80",
              "name": "SNAC P1,P2->P1,P2"
            },
            {
              "value": "0xC0",
              "name": "SNAC P1,P2->P2,P1"
            },
            {
              "value": "0x200",
              "name": "SNAC P1,P2->P3,P4"
            },
            {
              "value": "0x100",
              "name": "SNAC P1-P4->P1-P4"
            },
            {
              "value": "0x140",
              "name": "SNAC P1-P2->P1-P2"
            },
            {
              "value": "0x180",
              "name": "SNAC P1-P2->P3-P4"
            }
        ]
    },
    {
        "name": "Analogizer Video Out",
        "id": 45,
        "type": "list",
        "enabled": true,
        "persist": true,
        "address": "0xA0000000",
        "defaultval": "0x0",
        "mask": "0xFFFFC3FF",
        "options": [
            {
              "value": "0x0",
              "name": "RGBS"
            },
            {
              "value": "0x0400",
              "name": "RGsB"
            },
            {
              "value": "0x0800",
              "name": "YPbPr"
            },
            {
              "value": "0x0C00",
              "name": "Y/C NTSC"
            },
            {
              "value": "0x1400",
              "name": "Scandoubler RGBHV"
            },
            {
              "value": "0x2000",
              "name": "RGBS,Pocket OFF"
            },
            {
              "value": "0x2400",
              "name": "RGsB,Pocket OFF"
            },
            {
              "value": "0x2800",
              "name": "YPbPr,Pocket OFF"
            },            {
              "value": "0x2C00",
              "name": "Y/C NTSC,Pocket OFF"
            },
            {
              "value": "0x3400",
              "name": "Scandoubler,Pocket OFF"
            }
        ]
    },
    ...
        ],
    "messages": []
  }
}
```

De forma esquematizada estas serían las diferentes opciones que se pueden seleccionar para Analogizer:

```
  SNAC Adapter
    |                            FUNCTION                    VALUE (hex) WIDTH ADDRESS    MASK       MASKED VALUE
    +----------- None            disables SNAC interface     0x0         5     0xA0000000 0xFFFFFFE0 0x00        
    +----------- DB15 Normal     1/2 players                 0x1         5     0xA0000000 0xFFFFFFE0 0x01        
    +----------- NES             1/2 players                 0x2         5     0xA0000000 0xFFFFFFE0 0x02        
    +----------- SNES            1/2 players                 0x3         5     0xA0000000 0xFFFFFFE0 0x03         
    +----------- PCE 2BTN        1 player                    0x4         5     0xA0000000 0xFFFFFFE0 0x04         
    +----------- PCE 6BTN        1 player                    0x5         5     0xA0000000 0xFFFFFFE0 0x05         
    +----------- PCE Multitap    allows 4 players            0x6         5     0xA0000000 0xFFFFFFE0 0x06         
    +----------- DB15 Fast       uses faster sampling        0x9         5     0xA0000000 0xFFFFFFE0 0x09         
    +----------- SNES A,B<->X,Y  swap A,B X,Y buttons        0xB         5     0xA0000000 0xFFFFFFE0 0x0B         
``` 

```
  SNAC Controller Assignment 
    |                              FUNCTION                                       VALUE (hex) WIDTH ADDRESS    MASK       MASKED VALUE
    +----------- SNAC -> P1        SNAC controller to P1                          0x0         4     0xA0000000 0xFFFFFC3F 0x000                 
    +----------- SNAC -> P2        SNAC controller to P2                          0x1         4     0xA0000000 0xFFFFFC3F 0x040           
    +----------- SNAC P1,P2->P1,P2 SNAC cont1,cont2 to P1,P2                      0x2         4     0xA0000000 0xFFFFFC3F 0x080           
    +----------- SNAC P1,P2->P2,P1 SNAC cont1,cont2 to P2,P1                      0x3         4     0xA0000000 0xFFFFFC3F 0x0C0           
    +----------- SNAC P1,P2->P3,P4 SNAC cont1,cont2 to P3,P4 (only for 4P cores)  0x8         4     0xA0000000 0xFFFFFC3F 0x200           
    +----------- SNAC P1-P4->P1-P4 SNAC cont1-cont4 to P1-P4 (only for 4P cores)  0x9         4     0xA0000000 0xFFFFFC3F 0x100           
    +----------- SNAC P1-P2->P1-P2 SNAC cont1-cont2 to P1-P2 (only for 4P cores)  0xA         4     0xA0000000 0xFFFFFC3F 0x140           
    +----------- SNAC P1-P2->P3-P4 SNAC cont1-cont2 to P3-P4 (only for 4P cores)  0xB         4     0xA0000000 0xFFFFFC3F 0x180                     
```

```
  Analogizer Video Out
    |                                   FUNCTION                    VALUE (hex) WIDTH ADDRESS    MASK       MASKED VALUE 
    +----------- RGBS                   idem                        0x0         4     0xA0000000 0xFFFFC3FF 0x0000       
    +----------- RGsB                   idem                        0x1         4     0xA0000000 0xFFFFC3FF 0x0400       
    +----------- YPbPr                  idem                        0x2         4     0xA0000000 0xFFFFC3FF 0x0800       
    +----------- Y/C NTSC               idem                        0x3         4     0xA0000000 0xFFFFC3FF 0x0C00       
    +----------- Y/C PAL                idem                        0x4         4     0xA0000000 0xFFFFC3FF 0x1000       
    +----------- Scandoubler RGBHV      idem                        0x5         4     0xA0000000 0xFFFFC3FF 0x1400       
    +----------- RGBS,Pocket OFF        idem, blanks Pocket screen  0x8         4     0xA0000000 0xFFFFC3FF 0x2000       
    +----------- RGsB,Pocket OFF        idem, blanks Pocket screen  0x9         4     0xA0000000 0xFFFFC3FF 0x2400       
    +----------- YPbPr,Pocket OFF       idem, blanks Pocket screen  0xA         4     0xA0000000 0xFFFFC3FF 0x2800       
    +----------- Y/C NTSC,Pocket OFF    idem, blanks Pocket screen  0xB         4     0xA0000000 0xFFFFC3FF 0x2C00       
    +----------- Y/C PAL,Pocket OFF     idem, blanks Pocket screen  0xC         4     0xA0000000 0xFFFFC3FF 0x3000       
    +----------- Scandoubler,Pocket OFF idem, blanks Pocket screen  0xD         4     0xA0000000 0xFFFFC3FF 0x3400         
```

Hay que seleccionar un rango de direcciones del bridge en el framework de la Pocket, en el ejemplo se ha reservado la dirección 0xA0000000 para Analogizer.
La interacción en el código queda a elección del desarrollador, en este ejemplo quedaría así:

```
  // for bridge write data, we just broadcast it to all bus devices
  // for bridge read data, we have to mux it
  // add your own devices here
  always @(*) begin
    casex (bridge_addr)
      default: begin
        bridge_rd_data <= 0;
      end
      32'h2xxxxxxx: begin
        bridge_rd_data <= sd_read_data;
      end
      32'hA0000000: begin //Analogizer settings
        bridge_rd_data <= {18'h0,analogizer_settings};
      end
      32'hF8xxxxxx: begin
        bridge_rd_data <= cmd_bridge_rd_data;
      end
    endcase
  end
```

```
 always @(posedge clk_74a) begin
    if (reset_delay > 0) begin
      reset_delay <= reset_delay - 1;
    end

    if (bridge_wr) begin
      casex (bridge_addr)
        32'h0: begin
          ioctl_download <= bridge_wr_data[0];
        end
        32'h4: begin
          save_download <= bridge_wr_data[0];
        end
        ...
        /*[ANALOGIZER_HOOK_BEGIN]*/
		32'hA0000000: analogizer_settings  <=  bridge_wr_data[13:0];
	    /*[ANALOGIZER_HOOK_END]*/
        ...
      endcase
    end
  end
```

Puede ser necesario sincronizar la lectura de las opciones, al utilizar dominios de reloj diferentes:

```
  /*[ANALOGIZER_HOOK_BEGIN]*/
  //Pocket Menu settings
  reg [13:0] analogizer_settings = 0;
  wire [13:0] analogizer_settings_s;

  synch_3 #(.WIDTH(14)) sync_analogizer(analogizer_settings, analogizer_settings_s, clk_sys_42_95);

  always @(*) begin
    snac_game_cont_type   = analogizer_settings_s[4:0];
    snac_cont_assignment  = analogizer_settings_s[9:6];
    analogizer_video_type = analogizer_settings_s[13:10];
  end
  /*[ANALOGIZER_HOOK_END]*/
```

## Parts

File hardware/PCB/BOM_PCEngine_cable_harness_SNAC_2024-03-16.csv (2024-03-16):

ID | Name | Designator | Footprint | Quantity | Manufacturer Part | Manufacturer | Supplier | Supplier Part | Price
1 | U237-091N-4BLVS20 | USB1 | USB3.0-A-SMD_U237-091N-4BLVS20 | 1 | U237-091N-4BLVS20 | XKB Connectivity(中国星坤) | LCSC | C2684720 | 0.281
2 | USB-301WD-ARY | USB2 | USB-TH_XUNPU_USB-301WD-ARY | 1 | USB-301WD-ARY | XUNPU(讯普) | LCSC | C2895025 | 0.325

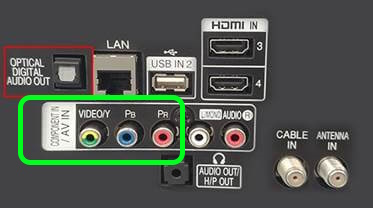
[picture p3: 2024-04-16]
img/entrada_video_componentes.jpg

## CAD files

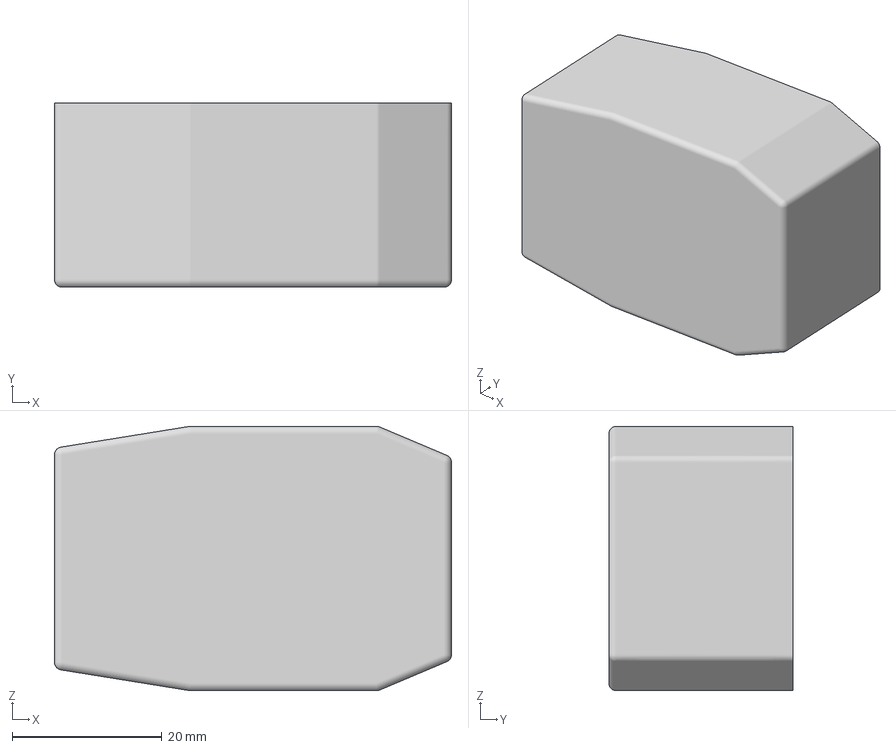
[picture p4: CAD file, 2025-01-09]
SNAC_CASES/nes-box.3mf
53.0 x 24.6 x 35.3 mm

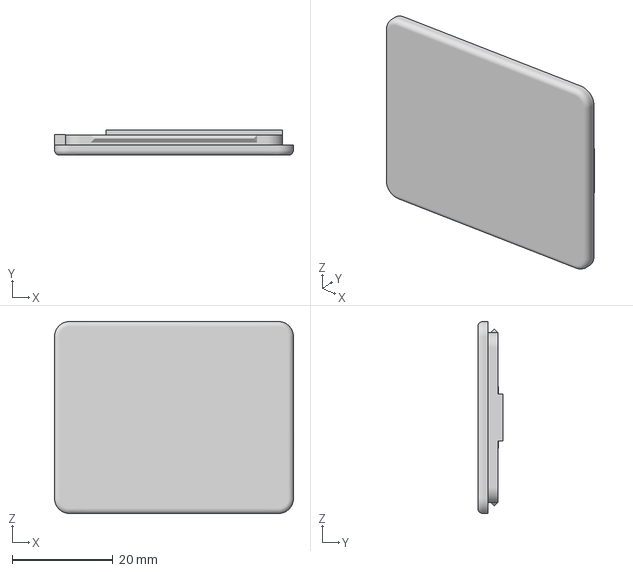
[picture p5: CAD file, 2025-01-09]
SNAC_CASES/SNES/snes-lid.3mf
47.4 x 5.00 x 38.1 mm

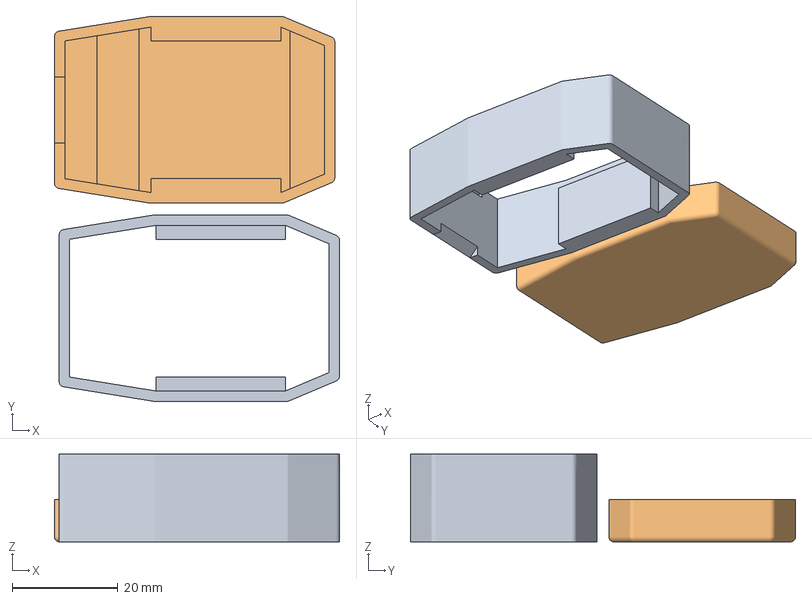
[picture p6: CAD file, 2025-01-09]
SNAC_CASES/NES_BASE.3mf
53.9 x 72.8 x 16.6 mm
Box_A
Box_B

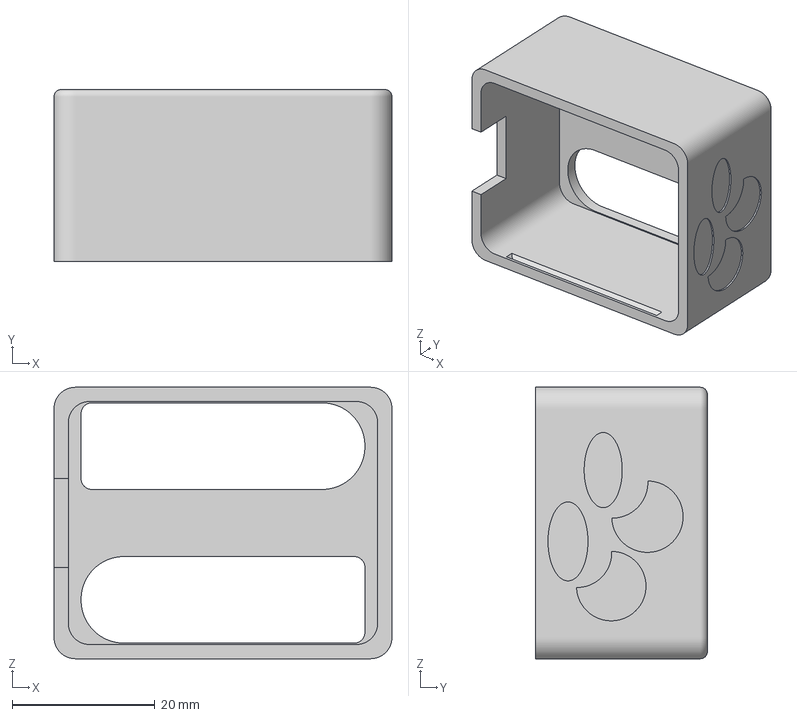
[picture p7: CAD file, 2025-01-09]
SNAC_CASES/SNES/snes-box.3mf
47.4 x 24.1 x 38.1 mm

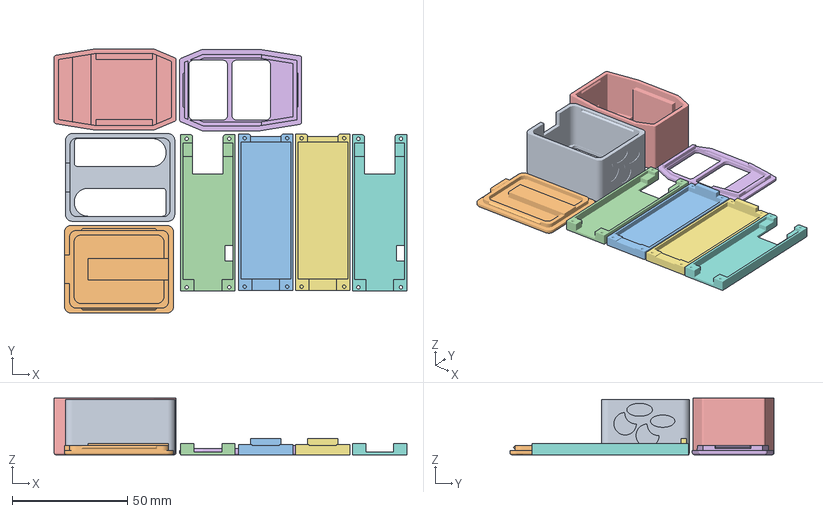
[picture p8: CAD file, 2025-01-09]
SNAC_CASES/SNAC bottom.3mf
153.1 x 114.6 x 24.6 mm
lid
SNAC bottom.stl x 2
SNAC top.stl x 2
Lid

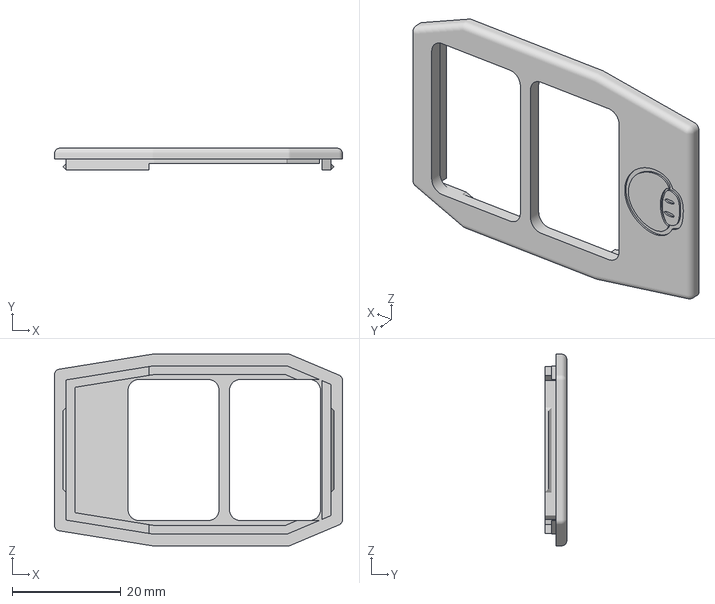
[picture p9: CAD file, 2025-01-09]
SNAC_CASES/nes-lid.3mf
53.0 x 4.00 x 35.3 mm

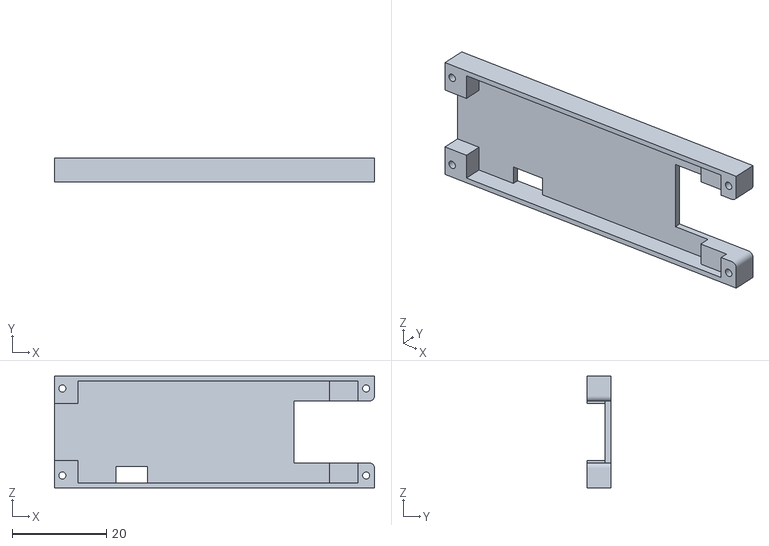
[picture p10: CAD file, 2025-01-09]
SNAC_CASES/SNAC top.stl
67.8 x 5.00 x 23.7

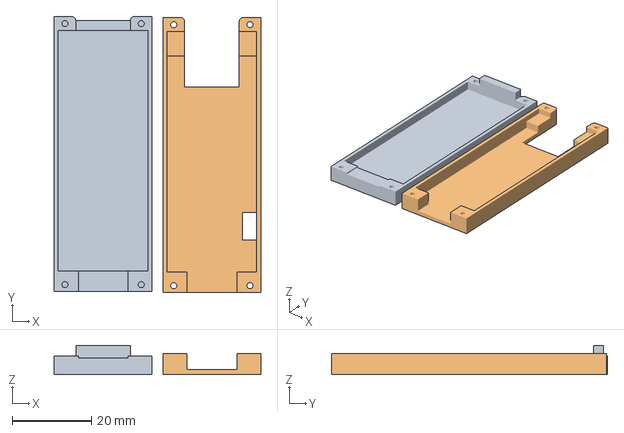
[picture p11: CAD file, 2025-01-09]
SNAC_CASES/SNAC_cases_BLUE212.3mf
52.0 x 69.5 x 7.40 mm
SNAC bottom.stl
SNAC top.stl

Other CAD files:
SNAC_CASES/SNAC bottom.stl

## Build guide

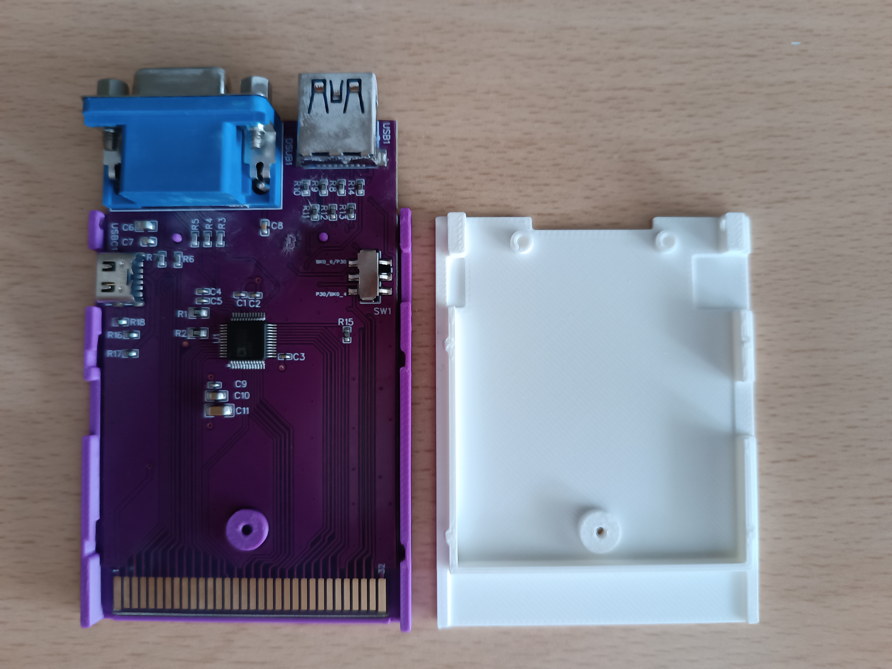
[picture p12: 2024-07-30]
case_mounting/Step02_Mounting_PCB.jpg

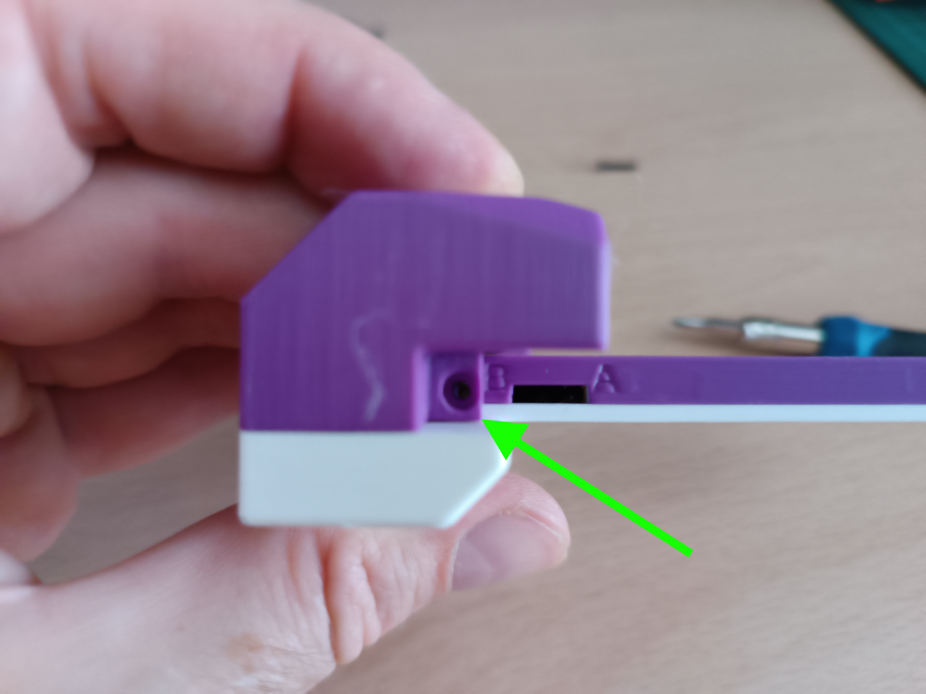
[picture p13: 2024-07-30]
case_mounting/Step07_Screw_case_sidesA.jpg

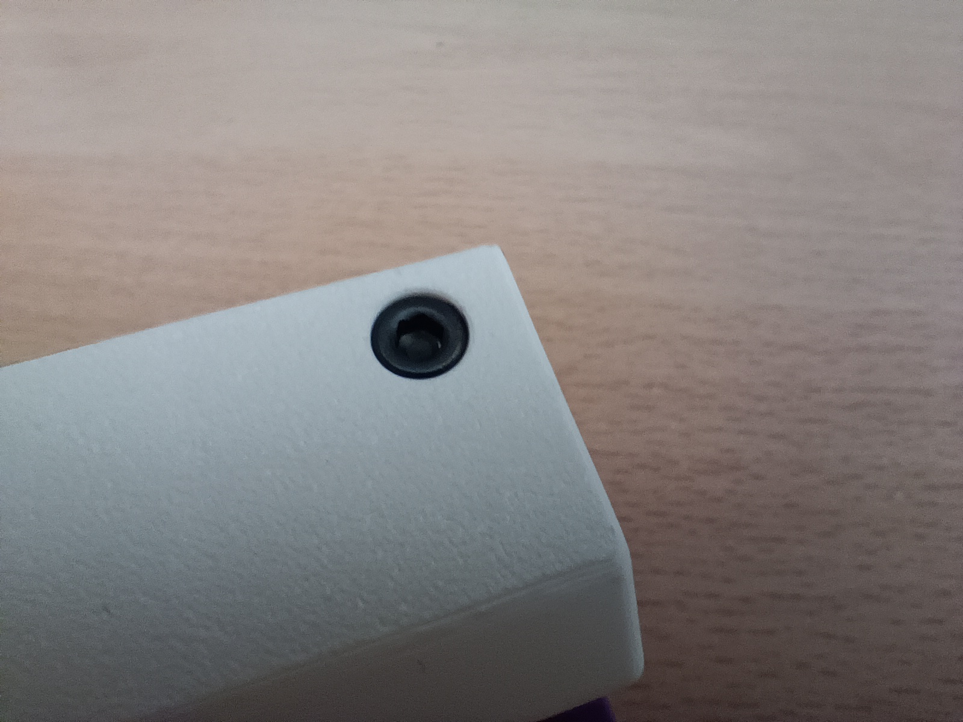
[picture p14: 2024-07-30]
case_mounting/Step08_Screw_case_Base_C.jpg

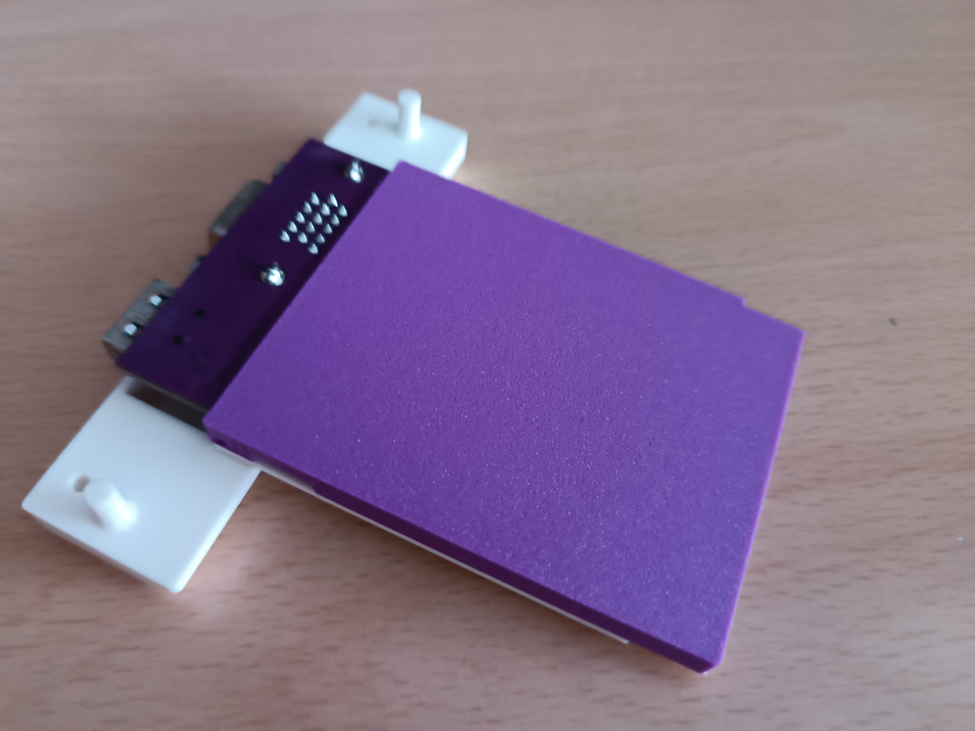
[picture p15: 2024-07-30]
case_mounting/Step04_Put_bottom_header_case_part.jpg

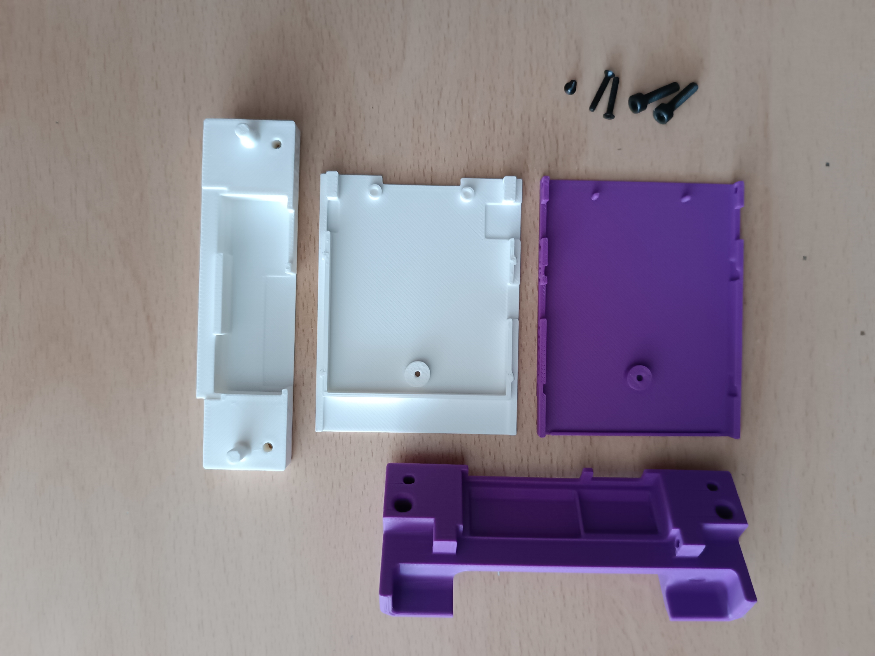
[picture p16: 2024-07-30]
case_mounting/Step01_Kit_contents.jpg

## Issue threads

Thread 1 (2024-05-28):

README_en.md may contain link to VGA -> SCART cable that may be unsuitable

janlavoie, 2024-05-28:
Hi,

While reading through the README_en.md, I noticed a potential issue/inconsistency with the spanish version (README.md).

Specifically, in the section "What do you need to use it?" :
After the explanation about VGA -> SCART, which mentions the recommendation for a particular cable because :

> It is recommended to use this cable with the Analogizer because it is verified that it takes the +5V from pin 9 of the VGA connector and passes it to pin 16 of the SCART

There is a list of links, 2 of them for VGA -> SCART cables :

- https://manuferhi.com/p/cable-rgb-scart-for-mister-mist-sidi-and-n-go
- https://ultimatemister.com/product/rgb-scart-cable/
- (more links)

The second link (https://ultimatemister.com/product/rgb-scart-cable/) contains a cable which seems unsuitable based on the following information in the linked page :

> - VGA pin 14 connects to SCART pin 16 directly (1,6v or less, no attenuation required)
> - Our cable does not use VGA PIN 9, works with MiSTer I/O set in 3.3v

When looking at the spanish README, that link in question is not present :

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

The link in question was added exclusively to the english readme in the following changeset :
https://github.com/RndMnkIII/Analogizer/commit/a6d653f981da6fd88093d54297811fb106a0b36a

---
Based on this, I believe this may have been a typo. I'm bringing it to your attention just in case it is indeed problematic.

Thank you very much for the work you are doing! Please accept my apologies if I misunderstood and am mistaken.
Best Regards,

RndMnkIII, 2024-05-28:
VGA pin 14(VSync) is tied to high state in the Analogizer interface for RGBS video output or 3.3V. I think this should work with this cable.

Closed 2024-05-28.

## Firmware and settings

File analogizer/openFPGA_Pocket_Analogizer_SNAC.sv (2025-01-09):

//This module encapsulates all Analogizer adapter SNAC controllers
// Original work by @RndMnkIII. 
// Date: 01/2024 
// Release: 1.0

// *** Analogizer R.1 adapter ***
//SNAC mappings:
//USB 3 Type A connector   ______________________________________________________________________________________                             
//PIN_NUMBER:             /           1      2       3       4       5       6       7       8       9           \
//PIN_NAME:              |             VBUS   D-      D+      GND     RX-     RX+     GND_D   TX-     TX+         |
//FUNCTION:              |             +5V    OUT1    OUT2    GND     IO3     IN4     IO5     IO6     IN7         |
//                       |  A                   ^       ^              ^       |       ^       ^       |          |
//                       |  N                   |       |              |       |    +--|-------|-------+          |
//                       |  A       +-----------|-------|--------------|-------+    |  |       +----------------+ |                              
//                       |  L       |         +-|-------|--------------|------------+  +--------+               | |            
//                       |  O       |         | |       |              |      +------------+    |               | |
//                       |  G       |         | |       |              |   +->| B        B |----|------+        | |
//                       |  I       |         | |       |              +---|->| CONF. SW.  |<---+      |        | |
//                       |  Z       |         | |   +---|-------<----------|<-| A        A |<----+     |        | |
//                       |  E       |         | |   |   |                  |  +------------+     |     |        | |
//                       |  R       |         | |   |   |             +-->-+------>--------->----+     |        | |         
//                       |         I|        I| |   |   +-------+     |                                |        | |
//                       |  R      N|        N| +---------+     |    B|A     B OUT                     |        | |
//                       |  1      4|   I    7|  IO3| OUT1| OUT2|  IO3|IO5  +-----------------------------------+ |
//                       |          |   O   IN|    A|     |O    |O   O|O    |A IN                      |          |  
//                       |         I|   5+----|-----|-----|U----|U---U|U ---|--------------------------+          |  
//                       |      ___N|___B|IN__|___IN|_____|T____|T___T|T____|_____                                |  
//POCKET                 |     /    V    V    V     V     ^     ^     ^     V     \                               |    
//CARTRIDGE PIN #:        \___|     2    3    4     5 ... 28    29    30    31     |_____________________________/
//                             \____|____|____|_____|_____|_____|_____|_____|_____/
//Pocket Pin Name:                  |    |    |     |     |     |     |     |
//cart_tran_bank0[7] ---------------+    |    |     |     |     |     |     | cart_tran_bank0_dir=1'b0; //input
//cart_tran_bank0[6] --------------------+    |     |     |     |     |     |
//cart_tran_bank0[5] -------------------------+     |     |     |     |     |
//cart_tran_bank0[4] -------------------------------+     |     |     |     |
//cart_tran_bank1[6] -------------------------------------+     |     |     | cart_tran_bank1_dir=1'b1 //output
//cart_tran_bank1[7] -------------------------------------------+     |     |
//cart_tran_pin30    -------------------------------------------------+     | cart_tran_pin30_dir=1'b1, cart_pin30_pwroff_reset=1'b1 (GPIO USE)
//cart_tran_pin31    -------------------------------------------------------+ cart_tran_pin31_dir=1'b0 / 1'b1 
//-------------------------------------------------------------------------------------------------------------------------------------------------------------------++------------------
//                                                      C O N F I G U R A T I O N   A                                                                                || CONFIGURATION  B
//-------------------------------------------------------------------------------------------------------------------------------------------------------------------++------------------
//     DEV TYPE          0                   1                    2                   3                   4                     5                 6                  || 16         
//     PIN_NAME         SNAC DISABLED        DB15		          NES                 SNES                PCENGINE(2BTN)        PCENGINE(6BTN)    PCENGINE(MULTITAP) || PSX
//USB3       SNAC                                                                                                                                                    || [NOT IMPLEMENTED]
//-------------------------------------------------------------------------------------------------------------------------------------------------------------------||------------------
//VBUS 		 	                             +5V                  +5V                 +5V                 +5V                   +5V               +5V                || +5V                 
//D-		 OUT1      	                     CLK(O)               CLK_1(O)            CLK_1(O)            CLR(O)(*)             CLR(O)(*)         CLR(O)(*)          || AT1(O)     
//D+		 OUT2      	                     LAT(O)               LAT(O)              LAT(O)              SEL(O)(*)             SEL(O)(*)         SEL(O)(*)          || AT2(O)     
//GND 		 	                             GND                  GND                 GND                 GND                   GND               GND                || GND     
//RX-		  IO3                            DAT(I)               D0_1(I)             D0_1(I)             D2 (I)(*)             D2 (I)(*)         D2 (I)(*)          || CLK(O)          +
//RX+		  IN4                                                 D4_2(I)             IO_2(I)             D0 (I)(*)             D0 (I)(*)         D0 (I)(*)          || DAT(I)      
//GND_DRAIN	  IO5                                                 CLK_2(O)            CLK_2(O)                                                                       || ACK(I)          +
//TX-		  IO6                            DAT(I)(1)            D3_2(I)             D3_2(I)             D1 (I)(*)             D1 (I)(*)         D1 (I)(*)          || CMD(O)          +    
//TX+		  IN7                            D0_2(I)              D0_2(I)             D3 (I)(*)           D3 (I)(*)             D3 (I)(*)         D3 (I)(*)          || IRQ10(I)      
//
//(1) Alternate output of DAT (for male-to-male extension cables which cross Tx,Rx lines)
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

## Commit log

2024-03-16 updated pcb design
    [PickAndPlace_PCB_PCEngine_cable_harness_SNAC_2024-03-16.csv]
2024-03-24 Added support for RGsB, YPbPr video output For R2 Analogizer
    [BOM_PCEngine_cable_harness_SNAC_2024-03-17.csv, PickAndPlace_PCB_PCEngine_cable_harness_SNAC_2024-03-17.csv]
2024-06-03 updated framework files
2024-06-03 relocated schematics and hardware files to hardware folder
    [BOM_PCEngine_cable_harness_SNAC_2024-03-16.csv, BOM_PCEngine_cable_harness_SNAC_2024-03-17.csv, PickAndPlace_PCB_PCEngine_cable_harness_SNAC_2024-03-16.csv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]
2024-06-16 Update openFPGA_Pocket_Analogizer.v
    fixed default pin value on reset state or with adapter disabled
2024-07-30 added mounting case images
2025-01-09 updated to include PSX SNAC controller
    updated to include PSX SNAC controller
    [NES_BASE.3mf, SNAC bottom.3mf, SNAC bottom.stl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]
